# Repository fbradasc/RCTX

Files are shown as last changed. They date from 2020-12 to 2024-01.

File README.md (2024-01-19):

# RCTX - Multi-band R/C System

**Multi-band** because it's designed to work in the following **R/C** frequencies bands:

| Frequency | MHz/GHz | Supported |
| :---: | :-----: | :---: |
| 13 | MHz | y |
| 27 | MHz | y |
| 30 | MHz | y |
| 35 | MHz | y |
| 40 | MHz | y |
| 50-55 | MHz | y |
| 70-75 | MHz | y |
| 433 | MHz | y |
| 440 | MHz | y |
| 460 | MHz | y |
| 866 | MHz | with an external module |
| 900 | MHz | with an external module |
| 2.4 | GHz | y |

**System** because it's composed by two components:
- the **Encoder** (the remote command)
- the **Decoder** (the receiver)

## Common hardware description
Both components are designed around the Silicon Labs' **EFR32MG12** (_Multi-Protocol Wireless SoC_).

The **EFR32MG12** is equipped with both a _2.4 GHz_ transceiver and a _Sub-GHz_ transceiver tunable as low as _110 MHz_.

To go as low as 13 MHz the Sub-GHz transceiver is configured to work in the _110-350 MHz_ wideband and coupled with the Mini Cicruits' **ADE-1+** (_bidirectional double balanched diode mixer_) with a _LO_ frequency of _110 MHz_, as for the following frequency conversion scheme:
```
 10- 80 -(+110)-> 120-190 band pass
430-460 -(-110)-> 320-350 band pass

    10       80           430     460
     +--...--+             +--...--+
    /         \           /         \        [ Antennas ]
   /           \         /           \
--+             +--...--+             +--

                    ^
                    |
                    v
             110 ->(X)                       [ ADE-1+ ]
                    ^
                    |
                    v
    120     190           320     350
     +--...--+             +--...--+
    /         \           /         \        [ EFR32MG12 Sub-GHz transceiver ]
   /           \         /           \
--+             +--...--+             +--
```

#### Half and full duplex modes
Each **EFR32MG12** transceiver works in ***half duplex*** mode but using both at the same time a ***full duplex*** link between the **Encoder** and the **Decoder** can be established.

For example, the **Encoder** transmits the commands to the **Decoder** via the *Sub-GHz* channel and at the same time the **Decoder** transmits the telemetry to the **Encoder** on the *2.4 GHz* channel:
| Data | direction | Channel |
| :--: | :--: | :--: |
| _Commands_ | Encoder **-->** Decoder | _Sub-GHz_ |
| _Telemetry_ | Encoder **<--** Decoder | _2.4 GHz_ |

#### Utilities

Both components are designed to have the following utilities:
| connector | functionality |
| :-- | :-- |
| micro USB | logs and/or control from the PC |
| SD card | firmware upgrade, logs, configurations and telemetry storage |
| buzzer | acoustic feedback |
| Nokia 5110 display | GUI and data visualization |
| serial-interfaced LED driver (MAX6969 or MAX6971) | optical feedback for digital controls |

These utilities are built around the _Silicon Labs'_ **EFM32HG310** microcontroller which acts as an UART bridge to the SD card, Nokia 5110 display, LEDs and buzzer from the **EFR32MG12** point of view and as a CMSIS-DAP, TTY and MSD (SD Card) USB adapter from the PC point of view.
```
[EFR32MG12] <--(SPI)--> [EFM32HG310] <--(USB)--> [PC]
                             ^
                             |
                           (SPI)
                             |
                             v
             ,----------+----+----+---------.
             ^          |         |         |
             |          |         |         |
             v          v         v         v
         [SD Card]  [BUZZER]  [display]  [LEDs]
```

## Encoder

The **Encoder**'s role is to transform the status of the following controls, switches and buttons into commands to be trasmitted to a **Decoder** or R/C receiver:

| Control | Count | Type | Note |
| :--- | :---: | :--- | :--- |
| Lever sticks | 4 | analog  | |
| Rotary controls | 12 | analog  | |
| On/Mom/Off Switches | 32 | analog  | converted from digital |
| Push buttons | 8 | analog  | converted from digital |
| Push buttons | 2 | digital | |

The commands are then incapsulated in a *protocol* and sent via a transmission channel to:

| Destination | Channel |
| :--- | :---: |
| a **Decoder** | Radio or ***TBD*** cable |
| a generic R/C receiver | Radio |
| another **Encoder** | DSC cable |
| a cable controlled device | I2C or UART cable  |

### ***Encoder*** configuration controls

The **Encoder**'s behaviour is controlled by a couple of DP3T (dual pole 3 pos) slide switches and 3 HEX selectors.

#### ***Encoder***'s output selection DP3T slide switch

This slide switch is used to select where the **Encoder**'s commands are sent:

| slide pos | on DSC cable | via radio | on serial cable |
| :---: | :---: | :---: | :---: |
| side 1 | X | | |
| center | | | X |
| side 2 | | X | |

#### Configurable DP3T slide switch - **TBD**

This slide switch behaviour can be configured by the user - **TBD**

#### ***RF BAND SEL*** HEX selector

This HEX selector is used to set the RF band on which the **Encoder** can be tuned for commands transmission and telemetry reception:

| HEX pos | RF band | MHz | GHz | Sub-GHz transceiver | GHz transceiver |
| :-----: | :--- | :-: | :-: | :---: | :---: |
| 0 | 13.560 |  X  | | ON: half-duplex | (1) |
| 1 | 26.815-27.995 |  X  | | ON: half duplex | (1) |
| 2 | 29.720-30.350 |  X  | | ON: half duplex | (1) |
| 3 | 34.945-36.600 |  X  | | ON: half duplex | (1) |
| 4 | 40.510-41.200 |  X  | | ON: half duplex | (1) |
| 5 | 49.830-50.980 |  X  | | ON: half duplex | (1) |
| 6 | 53.100-54.550 |  X  | | ON: half duplex | (1) |
| 7 | 70.140 |  X  | | ON: half duplex | (1) |
| 8 | 72.010 |  X  | | ON: half duplex | (1) |
| 9 | 75.410 |  X  | | ON: half duplex | (1) |
| A | 433.250 |  X  | | ON: half duplex | (1) |
| B | 434.025 |  X  | | ON: half duplex | (1) |
| C | 439.700 |  X  | | ON: half duplex | (1) |
| D | 458.500 |  X  | | ON: half duplex | (1) |
| E | 459.500 |  X  | | ON: half duplex | (1) |
| F | 2.4 | |  X  | OFF | ON: half duplex |

(1): Can be configured to be **ON: half duplex** for **Decoder**s which send on the 2.4 GHz band the *telemetry* back to the **Encoder**

#### ***RX ID*** and ***RX SUB ID*** HEX selectors

The **Encoder**'s custom trasmission protocol is composed by commands packets which can be addressed to up to 256 recipients.

This means that on a given frequncy, and bound to the **Encoder** at the same time, can be tuned:

- Up to 16 (**RX ID**) **Decoder**s each one with up to 15 (**RX SUB ID**) aditional addressable sub modules
- Up to 256 (**RX ID**:**RX SUB ID**) **Decoder**s with no sub modules

#### Robbe/Futaba F14 radio with RCTX mods

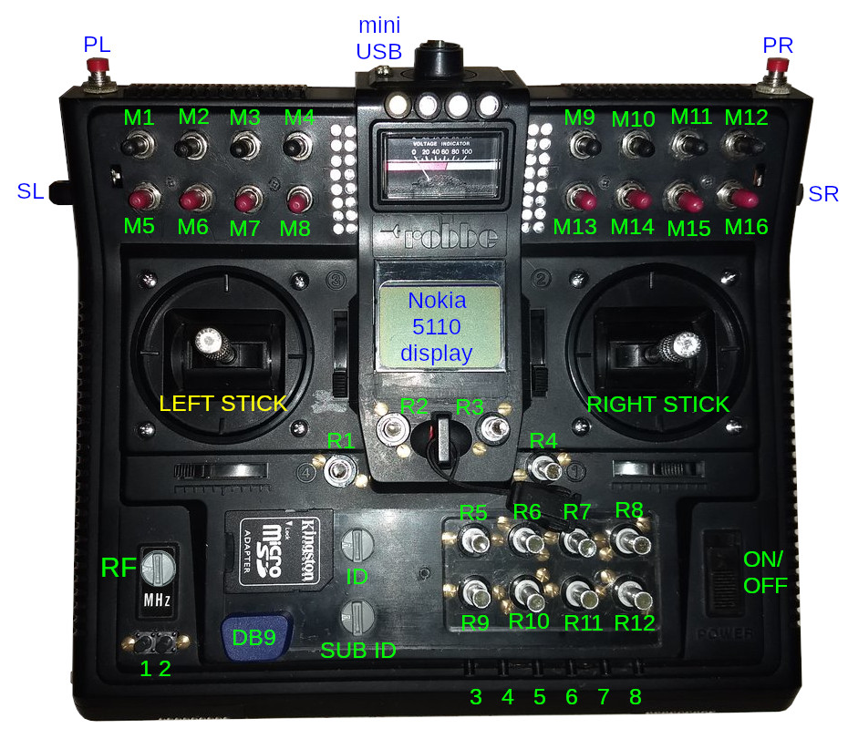
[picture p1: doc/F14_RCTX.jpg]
Robbe/Futaba F14 radio with RCTX mods


|#|Description|Reference on the picture|
|:-:|:-|:-|
|10|micro push buttons|**1** to **8**, **PL** and **PR**|
|16|*Mom-OFF-Mom* switches|**M1** to **M16**|
|2|*DP3T* slide switches|**SL** and **SR**|
|2|R/C sticks|**LEFT STICK** and **RIGHT STICK**|
|12|rotary controls|**R1** to **R12**|
|1|amperometer|**battery level indicator**|
|36|LEDs|on the side and above the **battery level indicator**|
|1|display|**Nokia 5110 display**|
|1|USB connector|**mini USB**|
|1|DB9 connector|flash programming and debug connections|
|1|DB15 connector|on the bottom side of the radio, expansion port with **UART**, **I2C**, **DSC** and tranceivers' mode connections|
|1|micro SD slot|**Kingston micro SD Card adapter**|
|3|hexadecimal encoders|**RX *ID***, **RX *SUB ID*** and ***RF* BAND SEL**|
|1|power switch|**ON/OFF**|

## Decoder

The **Decoder**'s main role is to produce a stream of signals on the *CRSF (Crossfire) bus* to control the actuators attached to such communication bus.

To achieve this task the **Decoder** merges the data coming from the sensors attached to its I2C bus with the commands trasmitted by the **Encoder** (either via radio or via ***TBD*** cable.

The **Decoder**, if configured, then compresses the sensors data and the signals produced in a format suitable to be stored on the SD card and to be transmitted back to the **Encoder** as ***telemetry*** data.

### Decoder configuration controls

The **Decoder**'s behaviour is controlled by 3 HEX selectors and a DIP switch.

#### ***RX ID*** and ***RX SUB ID*** HEX selectors

These HEX selectors are used to set the **Decoder**'s address.
Only the commands addressed to its own address (**RX ID** and **RX SUB ID** positions) are processed.

#### ***RF BAND SEL*** HEX selector

This HEX selector is used to set the RF band on which the **Decoder** can be tuned for commands reception and telemetry transmission:

| HEX pos | RF band | MHz | GHz | Sub-GHz transceiver | GHz transceiver |
| :-----: | :--- | :-: | :-: | :---: | :---: |
| 0 | 13.560 |  X  | | ON: half-duplex | (1) |
| 1 | 26.815-27.995 |  X  | | ON: half duplex | (1) |
| 2 | 29.720-30.350 |  X  | | ON: half duplex | (1) |
| 3 | 34.945-36.600 |  X  | | ON: half duplex | (1) |
| 4 | 40.510-41.200 |  X  | | ON: half duplex | (1) |
| 5 | 49.830-50.980 |  X  | | ON: half duplex | (1) |
| 6 | 53.100-54.550 |  X  | | ON: half duplex | (1) |
| 7 | 70.140 |  X  | | ON: half duplex | (1) |
| 8 | 72.010 |  X  | | ON: half duplex | (1) |
| 9 | 75.410 |  X  | | ON: half duplex | (1) |
| A | 433.250 |  X  | | ON: half duplex | (1) |
| B | 434.025 |  X  | | ON: half duplex | (1) |
| C | 439.700 |  X  | | ON: half duplex | (1) |
| D | 458.500 |  X  | | ON: half duplex | (1) |
| E | 459.500 |  X  | | ON: half duplex | (1) |
| F | 2.4 | |  X  | OFF | ON: half duplex |

(1): Can be configured to be **ON: half duplex** for **Decoder**s which send on the 2.4 GHz band the *telemetry* back to the **Encoder**.

#### ***RX RADIO EN*** DIP switch

This DIP switch is used to set the ***Decoder***'s source for incoming commands:

- **RX RADIO EN** in position ***1*** *(open)*

    The **Decoder** listens for commands signal on the **DSC_BUS** bus:
    - Turns OFF the radio transceiver.
    - Commands signal can only be received from the ***DSC_BUS***.
    - Telemetry data can only be send to the ***DSC_BUS***.

- **RX RADIO EN** in position ***2*** *(closed)*

    The **Decoder** listens for commands coming from the radio:
    - Turns ON the radio tranceivers.
    - Commands signal can only be received from the radio transceiver.
    - Commands signal received from the radio transceiver is mirrored, as is, over the ***DSC_BUS***.
    - Telemetry data can only be send to the radio transceiver.
    - Telemetry data received from the ***DSC_BUS*** is fused with the local telemetry data before it's sent to the radio transceiver.

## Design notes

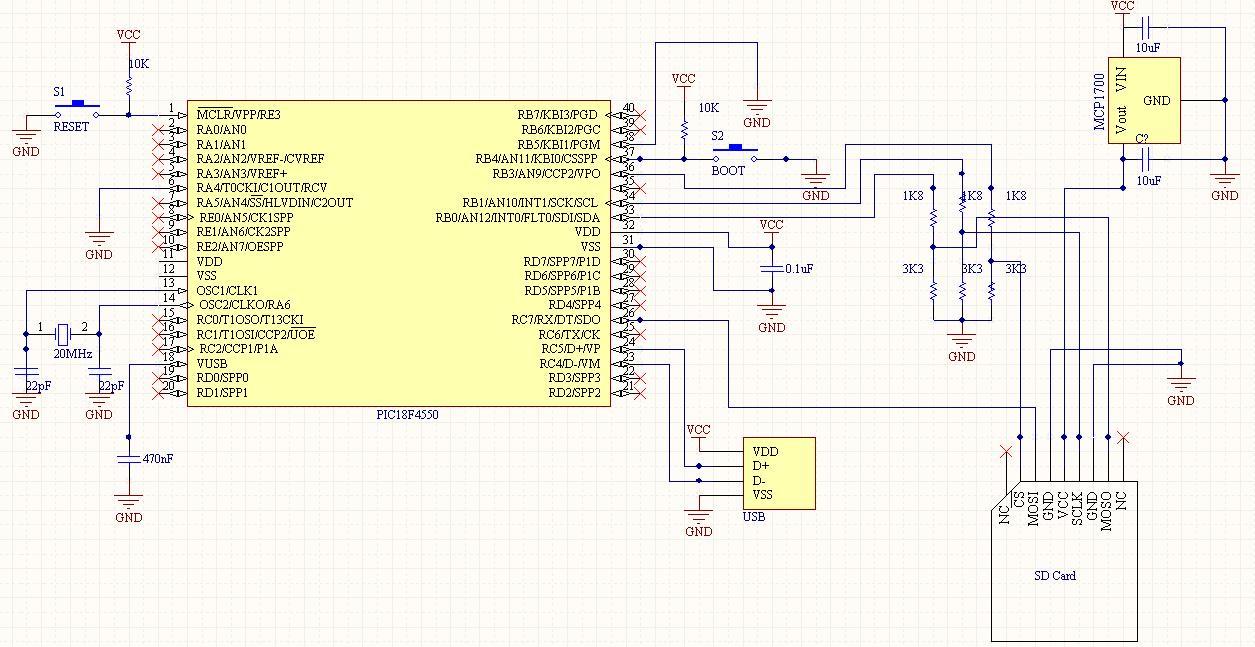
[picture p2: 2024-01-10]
doc/PIC/327320-Schematic.JPG

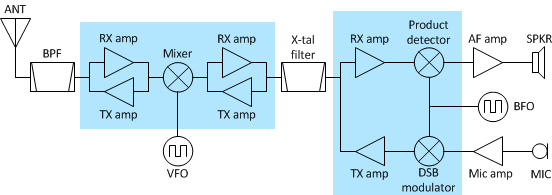
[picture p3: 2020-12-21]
doc/trx_blockdiagram.png

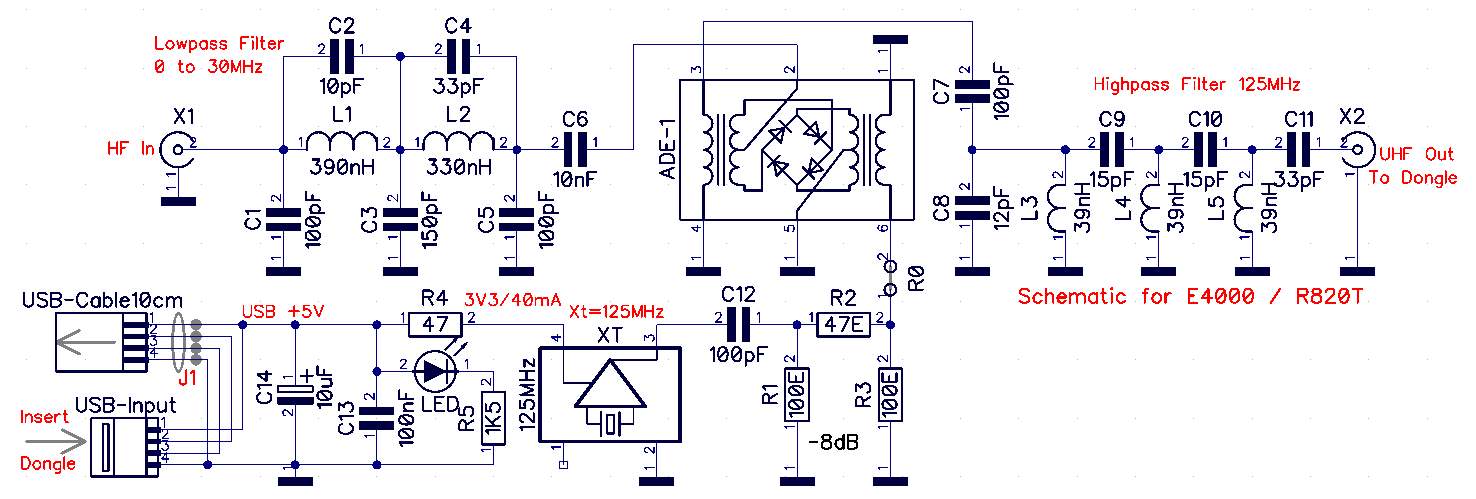
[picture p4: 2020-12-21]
doc/hf_con1_ade1_125_sch.gif

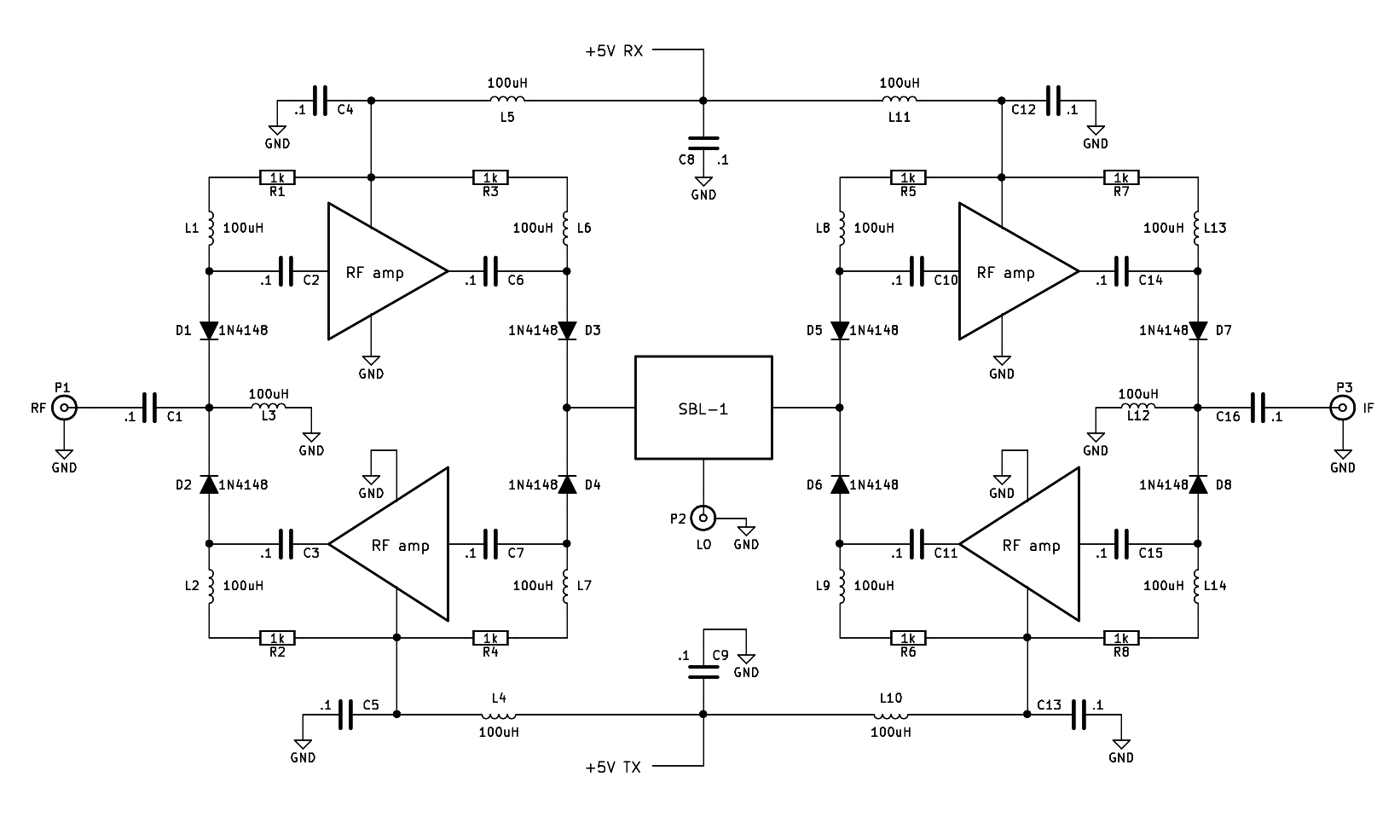
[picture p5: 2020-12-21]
doc/trx_mix_sch.png

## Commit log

2019-09-24 Adding new schematic for analog inputs board
    [RCTX_analog_board_3.sch]
2019-09-29 Adding kicad schematics
    [RCTX.sch, RCTX_JA.sch, RCTX_KPD.sch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]
2019-10-01 Adding 5110 display
    [RCTX.sch, RCTX_JA.sch, RCTX_KPD.sch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]
2019-10-10 Adding footprints
    [RCTX.kicad_pcb, RCTX.sch, RCTX_JA.sch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]
2020-08-05 Fixing keypad wiring
    [RCTX.sch, RCTX_JA.sch, RCTX_KPD.sch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]
2020-10-31 Adding Onsemi AX5043 based transmitter section
    [RCTX.sch, RCTX_JA.sch, RCTX_KPD.sch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]
2020-11-05 Adding tranceiver
    [RCTX.sch, RCTX_JA.sch, RCTX_KPD.sch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]
2020-11-07 AX5043 inductors values for RC frequencies
    [frequenze.xlsx]
2020-11-08 Using extended frequency ranges
    [frequenze.xlsx]
2020-12-13 Adding transceiver
    [RCTX.sch, RCTX_JA.sch, RCTX_KPD.sch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]
2020-12-20 New rx-tx bidirectional amplifier
    [SrfTransceiver.sch]
2020-12-31 Using ERF32FG12 SoC instead of PIC32MX
    [RCTX_JA.sch, RCTX_KPD.sch, RCTX_LEDS.sch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]
2021-01-01 Splitting leds in dispay schema
    [DisplayI2C.sch]
2021-01-10 Adding wideband (110-350 MHz) matching network
    [RCRX_ERF32MG12.sch, RCTX_ERF32MG12.sch]
2021-01-29 Using Pic16(L)F1459 as USB->(UART/SWD/I2C) bridge
    [AnalogSwitches.sch, RCRX_ERF32MG12.sch, RCTX_ERF32MG12.sch]
2021-02-07 Adding micro SD socket in RCRX board
    [AnalogSwitches.sch, DisplayI2C.sch, RCRX_ERF32MG12.sch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]
2021-03-21 Replacing Si500/Si510 clock generator with i2c controlled Si514 model
    [AnalogSwitches.sch, RCRX_ERF32MG12.sch, RCTX_ERF32MG12.sch]
2021-09-24 Replacing discrete components rf filters with Mini-Circuits single chip filters
    [RCRX_ERF32MG12.sch, RCTX_ERF32MG12.sch]
2021-10-07 Choosing filter for low frequences bands
2023-05-26 Refactoring SD card and LCD control
    [AnalogSwitches.kicad_sch, DisplayI2C.kicad_sch, RCRX_ERF32MG12.kicad_sch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]
2023-05-27 Adding PIB USB BRIDGE UML state diagrams
    [AnalogSwitches.kicad_sch, DisplayI2C.kicad_sch, RCRX_ERF32MG12.kicad_sch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]
2023-05-30 Adding PIB USB BRIDGE UML state diagrams - WIP
    [RCRX_ERF32MG12.kicad_sch, RCTX.kicad_sch, RCTX_JA.kicad_sch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]
2023-06-04 Adding PIC docs
    [RCRX_ERF32MG12.kicad_sch]
2023-06-05 Reset PIC by cutting off Vdd via a n/c SW instead of grounding the USB VBUS on Vpp via a n/o SW
    [RCRX_ERF32MG12.kicad_sch, RCTX_ERF32MG12.kicad_sch]
2023-06-08 Changing the buzzer connector
    [RCRX_ERF32MG12.kicad_sch, RCTX_ERF32MG12.kicad_sch]
2023-12-01 Using an930.1-efr32-series-1_2.4GHz-matching-guide.pdf values for 2.4 GHz matching network
    [RCTX_ERF32MG12.kicad_sch]
2023-12-07 Using MAX6969/MAX6971 SPI LEDs driver
    [DisplayI2C.kicad_sch, RCTX_ERF32MG12.kicad_sch]
2023-12-07 Optimizing power lines
    [AnalogSwitches.kicad_sch, Leds.kicad_sch, RCTX_ERF32MG12.kicad_sch]
2023-12-13 Using SAMD11D14M instead of PIC16F1459 for USB bridge - updating schematics
    [RCTX_ERF32MG12.kicad_sch]
2023-12-15 Driving the EFR32 reset with the SAMD11 reset pin as GPIO to have an additional GPIO for the SPI {EFR32<->SAMD11} CLK
    [RCRX_ERF32MG12.kicad_sch, RCTX_ERF32MG12.kicad_sch]
2023-12-15 Adding micro SD card slot in RX circuit
    [RCRX_ERF32MG12.kicad_sch]
2023-12-22 Using EFM32HG310-QFN32 instead of SAMD11D14M for USB bridge - updating schematics
    [RCRX_ERF32MG12.kicad_sch, RCTX_ERF32MG12.kicad_sch]
2023-12-31 Using 8x4 sqaure symbol for EFM32HG310-QFN32
    [RCRX_ERF32MG12.kicad_sch, RCTX_ERF32MG12.kicad_sch]
2024-01-08 Updated README.txt for EFM32HG310 SPI extender / USB bridge
    [AnalogSwitches.sch, DisplayI2C.kicad_sch, DisplayI2C.sch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]
2024-01-10 Updated the README.md with the preliminary description of the project
    [Leds.kicad_sch]
2024-01-11 Added HEX rotary encoder and DIP switch for RX SUB ID selection in the receiver circuit. Updated README.md
    [RCRX_ERF32MG12.kicad_sch]
2024-01-19 Update README.md Updated the Decoder description
    [RCRX_ERF32MG12.kicad_sch, RCTX_ERF32MG12.kicad_sch]
